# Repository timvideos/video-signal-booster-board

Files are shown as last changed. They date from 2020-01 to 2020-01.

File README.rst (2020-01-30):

Video Booster Board
===================

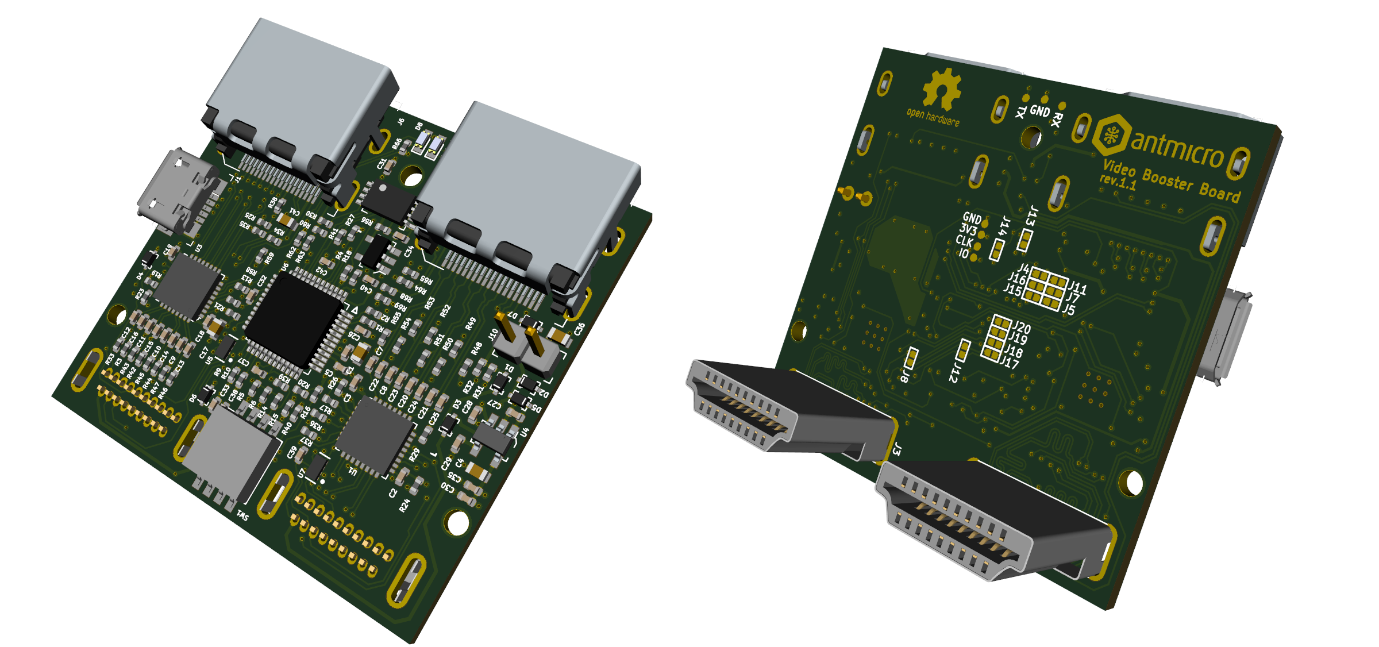
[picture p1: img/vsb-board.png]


Overview: 
---------

This repository contains a KiCad PCB project for an open hardware board design that allows to improve the quality of HDMI video signals transmitted over long cables.

Key features: 
-------------

* HDMI signal preconditioning with a pair of `PTN3363 <https://www.nxp.com/docs/en/data-sheet/PTN3363.pdf>`_ HDMI level shifters.
* Signal equalization controlled with on-board DIP-Switch
* On-board SiLabs `EFM32HG322F64 <https://www.silabs.com/documents/public/data-sheets/efm32hg-datasheet.pdf>`_ MCU for interactive control and board monitoring
* Supports different EDID connection scenarios

Mechanical layout and dimensions
--------------------------------

The board has been mechanically optimised for usage with the `Numato Opsis <https://hdmi2usb.tv/numato-opsis/>`_ open video capture device.
It is possible to use it with different platforms using HDMI extender cables.

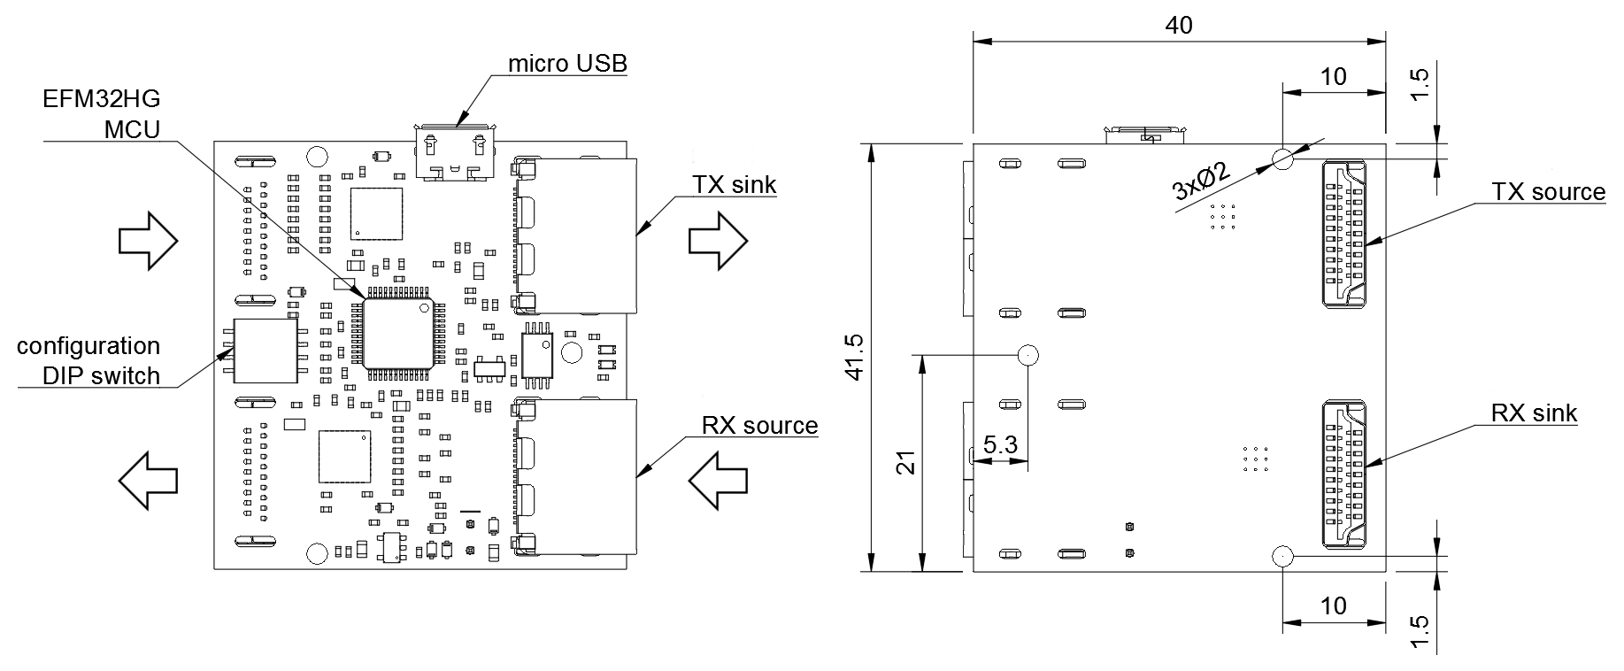
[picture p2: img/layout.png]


It follows the data flow diagram presented below:



Getting Started
---------------

Please refer to KiCad schematic files for more information regarding hardware functionalities implemented in the design.
The PCB layout has been defined with a 4-layer stackup.
Please check the geometry of differential traces implemented in the design with stackup offered by PCB vendor for optimal impedance match of HDMI traces.
There is a BOM document generated from the schematics and shared in this repository.
Please short the ``J5,J7,J8,J12`` solder jumpers on the bottom side of the PCB.
This will relay the EDID signals on both HDMI channels from input to output.
Short the ``J11,J4`` jumpers if you plan to experiment with the provided example MCU firmware.
This will make the on-board MCU accessible on EDID bus driven from ``J2`` HDMI input connector.
Please check the schematics and software codebase for any other jumper configuration.

Example firmware
----------------

The EFM32 MCU used in the design comes with a factory programmed ``AN0042`` bootloader.
In order to  make the MCU compatible with the provided example firmware it is advisable to replace the default bootloader with `Toboot <https://github.com/im-tomu/toboot>`_ 
over SWD interface using `OpenOCD <http://openocd.org/>`_.
The SWD signals from the MCU are exposed on test pads marked with ``IO`` and ``CLK`` on the bottom side of the Video Booster Board.
Additionally there are test pads with system ground and power supply exposed next to them.

To upload the ``Toboot`` bootloader, please follow this `instruction <https://github.com/im-tomu/toboot/tree/master/openocd>`_.
Be aware that the provided flashing instruction was originally created for a different hardware platform so the SWD connection wiring differs a little.

There is an ``example-firmware`` folder included in this repository, which contains a sample firmware driven by the RTOS derived from the `Zephyr project <https://www.zephyrproject.org/>`_.
The firmware makes the on-board EFM32 MCU act as an EDID slave for the transmitting device.

In order to build the example firmware please use the following commands::

     git clone https://github.com/antmicro/video-signal-booster-board
     cd video-signal-booster-board
     git submodule update --init --recursive
     cd example-firmware      
     python3 -m pip install -r zephyr/scripts/requirements.txt                                    
     wget https://github.com/zephyrproject-rtos/sdk-ng/releases/download/v0.10.3/zephyr-sdk-0.10.3-setup.run
     chmod +x zephyr-sdk-0.10.3-setup.run                                  
     ./zephyr-sdk-0.10.3-setup.run -- -d <zephyr_installation_path>                      
     export ZEPHYR_TOOLCHAIN_VARIANT=zephyr                                
     export ZEPHYR_SDK_INSTALL_DIR=<zephyr_installation_path>
     source zephyr/zephyr-env.sh
     west init -l zephyr
     west update
     make

Once the firmware is compiled, connect the micro USB cable to the Video Booster Board and upload the firmware using the following command::

     dfu-util -d 1209:70b1 -D build/zephyr/zephyr.bin

Please note that in this setup the firmware doesn't stick permanently. After a power cycle a bootloader will start again. This simplifies the developing process.

The example firmware makes the MCU on Video Booster Board accessible on I2C/EDID bus slave device under the address of ``0x3a`` (7-bit notation).
It's possible to test the I2C/EDID communication by connecting an I2C master device to TX source HDMI connector (``J2``).
The example firmware makes MCU offer a single 8-bit configuration register.
Two least significant bits of this register control the states of the ``TX_EQ0`` and ``TX_EQ1`` signals that define the equalization settings of ``U3`` HDMI level shifter.
The states of those signals are also displayed on ``D8`` ``D9`` LEDs installed on board.

A sample Python code that would drive the MCU over I2C bus is::

     python
     import smbus
     bus = smbus.SMBus(<i2c_bus_number>)
     bus.write_byte_data(0x3a, 0x00, 0x03)

3D-printable enclosure
----------------------

There is also a 3D-printable enclosure available in the ``3d-models`` directory.
The enclosure allows the electronics to be covered and attaches the Video Booster Board to the Numato board installed in a typical thin mini-ITX chassis.

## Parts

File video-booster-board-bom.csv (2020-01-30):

Id | Designator | Package | Quantity | Designation
1 | J9,J6 | HDMI_A_Female_685119134923 | 2 | 685119134923_
2 | R68,R20,R64,R62,R25,R27,R18 | 0402-res | 7 | R_27k_0402
3 | J12,J5,J14,J13,J8,J7 | SolderJumper-0.6x1.4mm | 6 | solder_jumper
4 | J3,J2 | CHDMI-AMSS-01-C-Vertical-mod1 | 2 | CHDMI-AMSS-01-C-Vertical
5 | U2 | TSSOP-8_W4.4mm | 1 | TPS2110APW
6 | CLK,IO,3V3,GND | Testpoint_smd_0_75mm | 4 | TP_SMD_0_75MM
7 | R21,R32,R35,R59,R58,R23,R26,R29,R34,R36,R37,R39,R40,R31,R9,R10 | 0402-res | 16 | R_10k_0402
8 | C27,C32,C40,C39,C38,C31,C33,C35,C2,C7,C8,C25,C24,C23,C22,C21,C20,C3,C12,C9,C10,C11,C19,C18,C16,C15,C14,C13 | 0402-cap | 28 | C_100n_0402_6V3
9 | U6 | TQFP-48_7x7mm | 1 | EFM32HG322F64
10 | C5,C42,C34,C37,C26,C6 | 0402-cap | 6 | C_1u_0402
11 | U3,U1 | QFN-32-1EP_5x5mm | 2 | PTN3363
12 | SW1 | 1571983-5 | 1 | 1571983-5
15 | C41,C4,C17 | 0603-cap | 3 | C_10u_0603
16 | C30,C28 | 0402-cap | 2 | C_2u2_0402
17 | R63,R69,R65 | 0402-res | 3 | R_4k7_0402
18 | R60,R24,R5,R6,R14,R15,R19 | 0402-res | 7 | R_100k_0402
19 | J10 | PinHeader_1x2_P2.54mm | 1 | M20-9990246
20 | D6,D5,D4,D3,D2,D1,D7 | SOD-523 | 7 | BAT54-02V-V-G
21 | U7,U5 | PSON50P100X195X50-8N | 2 | NTS0102GT
22 | R67,R66 | 0402-res | 2 | R_330R_0402
23 | IC1 | SOT-23-5 | 1 | INA180A1IDBVT
24 | D9,D8 | LED_0603 | 2 | LG_L29K-G2J1-24-Z
25 | C36,C1 | 0603-cap | 2 | C_4u7_0603
26 | R56 | 0402-res | 1 | R_1R_0402
27 | R54,R51,R55,R43,R53,R52,R50,R49,R48,R47,R46,R44,R45,R3,R42,R33 | 0402-res | 16 | R_49R9_0402
28 | R30 | 0402-res | 1 | R_806k_0402
29 | R38,R41,R4,R16 | 0402-res | 4 | R_100R_0402
30 | C29 | 0402-cap | 1 | C_10n_0402
31 | R13,R17 | 0402-res | 2 | R_12k4_0402
32 | R2,R1 | 0402-res | 2 | R_15R_0402
33 | U4 | SOT-753 | 1 | LP2985-33DBVR
34 | J1 | USB_Micro_B_Female_0473460001 | 1 | 473460001

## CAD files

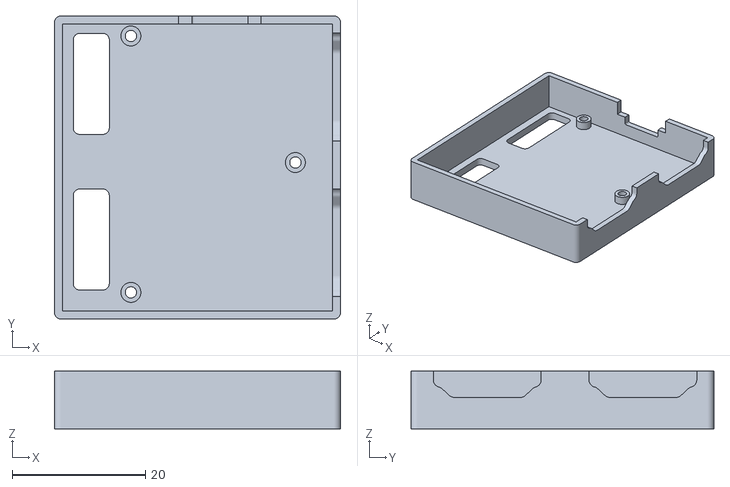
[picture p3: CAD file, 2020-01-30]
3dmodels/enclosure-bottom.stl
43.0 x 45.5 x 8.70

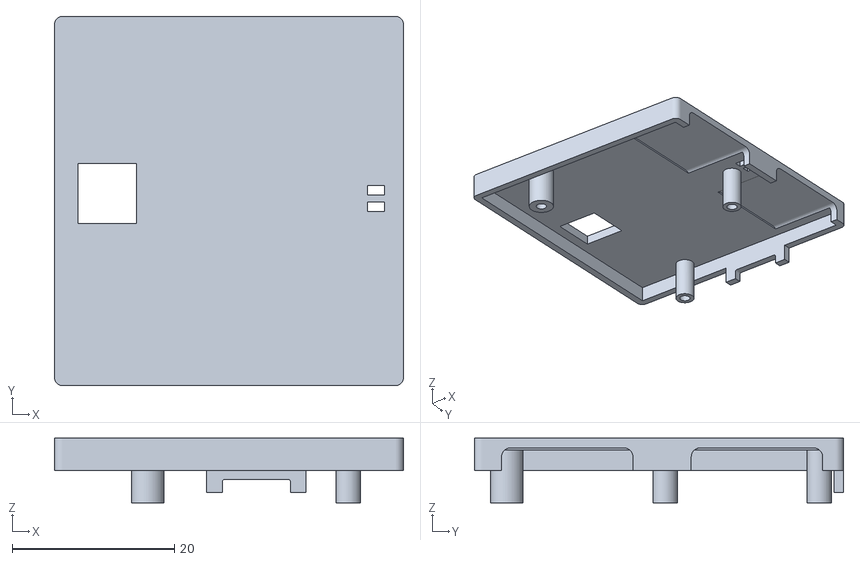
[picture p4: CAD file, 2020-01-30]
3dmodels/enclosure-top.stl
43.0 x 45.5 x 8.00

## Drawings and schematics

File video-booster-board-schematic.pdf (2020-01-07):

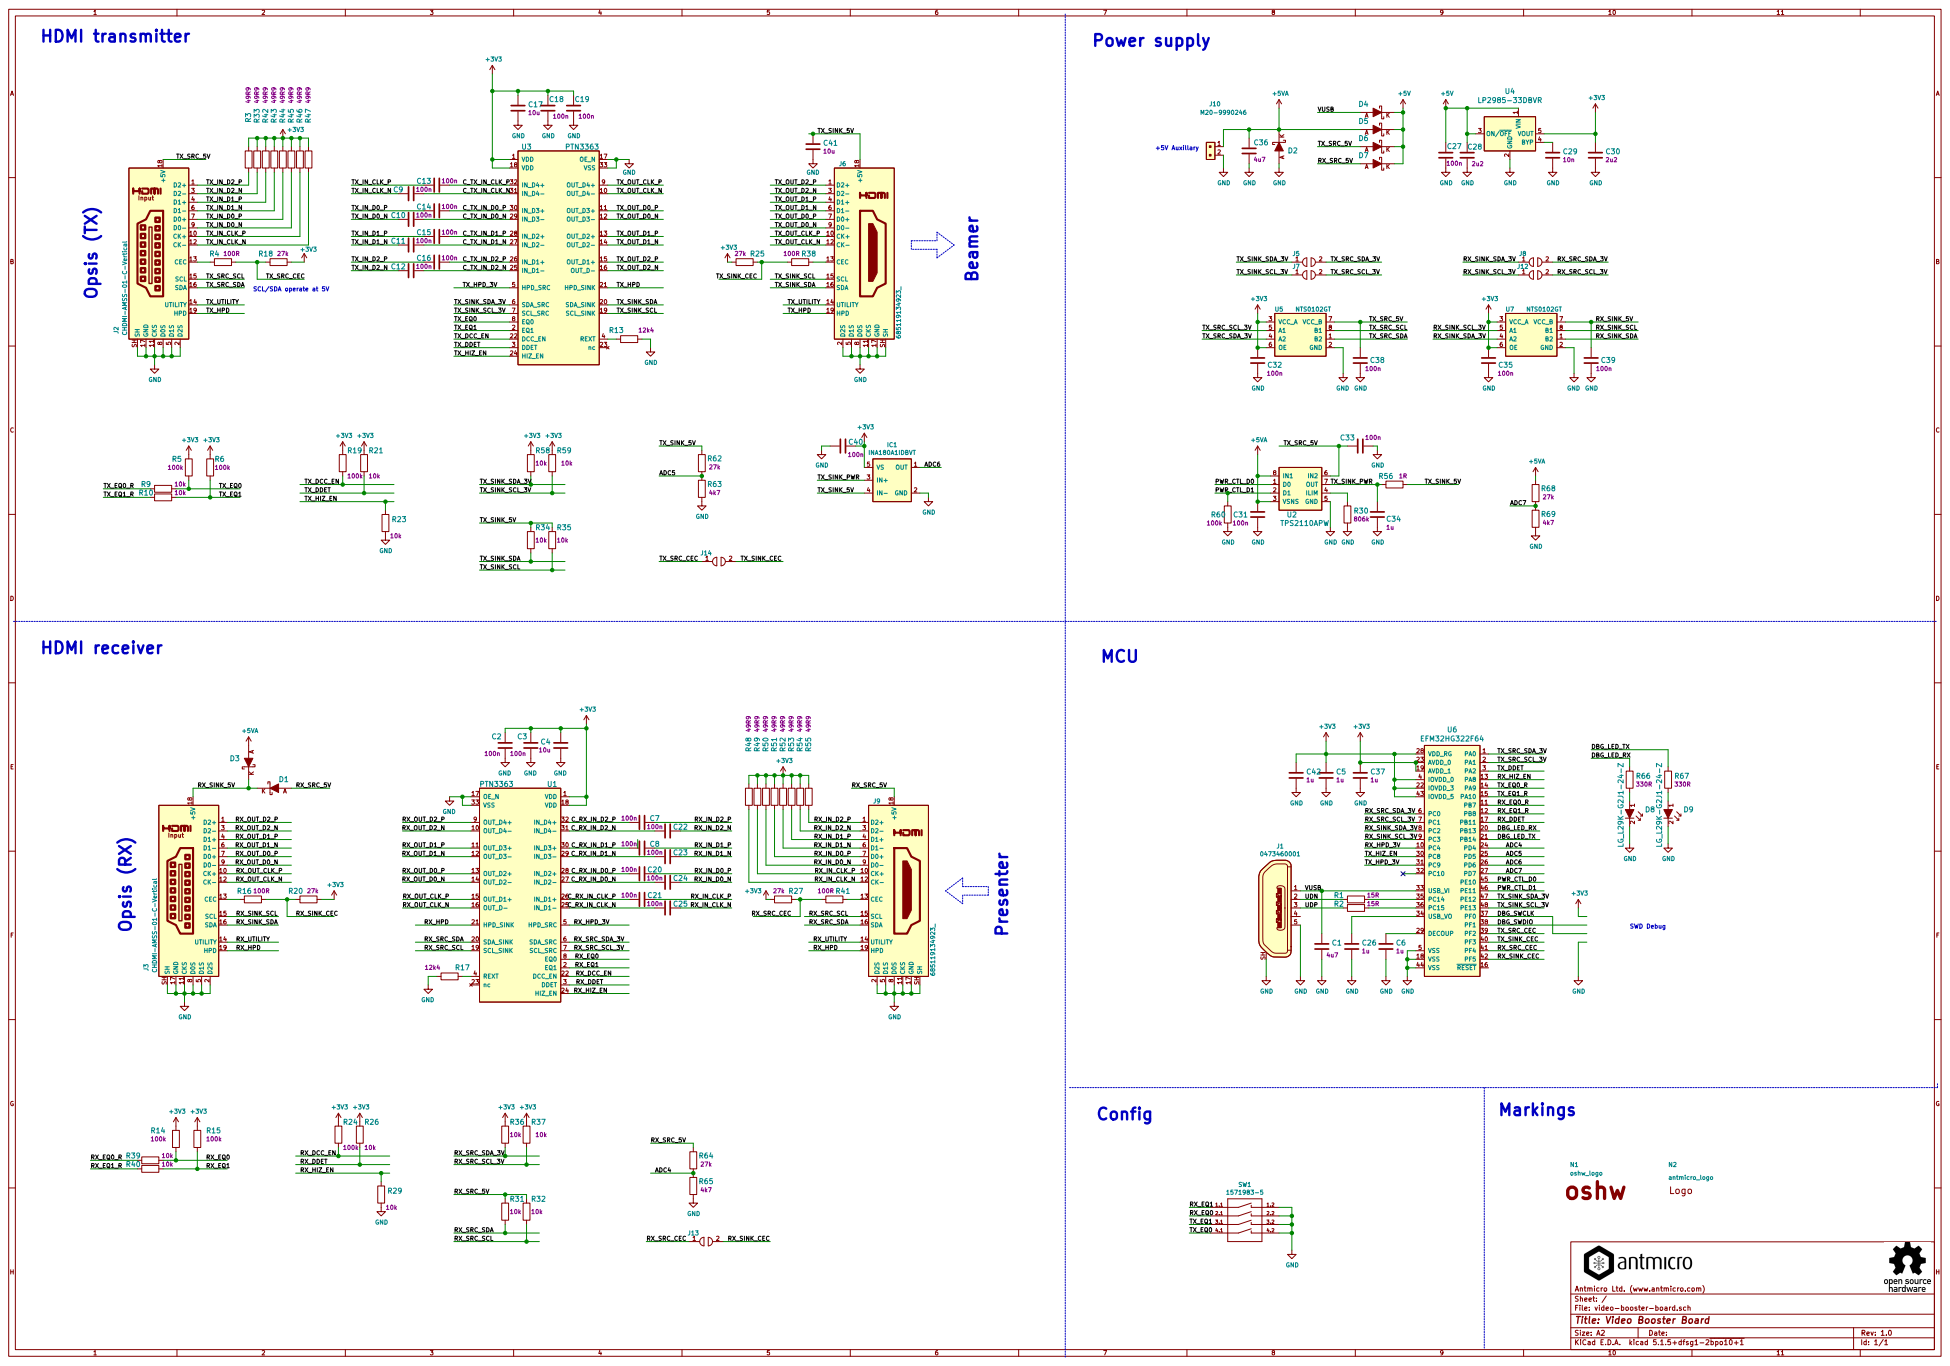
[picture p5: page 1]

8 D0- 9 SH SH J2CHDMI-AMSS-01-C-Vertical

8 D0- 9 SH SH J3CHDMI-AMSS-01-C-Vertical

File: video-booster-board.sch Sheet: / Antmicro Ltd. (www.antmicro.com)

Id: 1/1 Title: Video Booster Board

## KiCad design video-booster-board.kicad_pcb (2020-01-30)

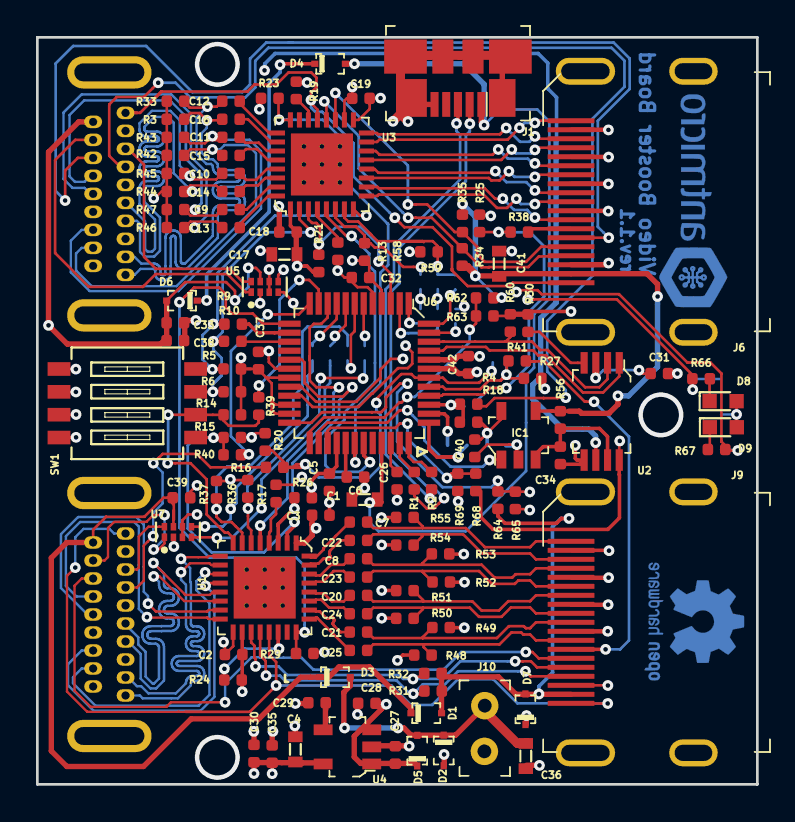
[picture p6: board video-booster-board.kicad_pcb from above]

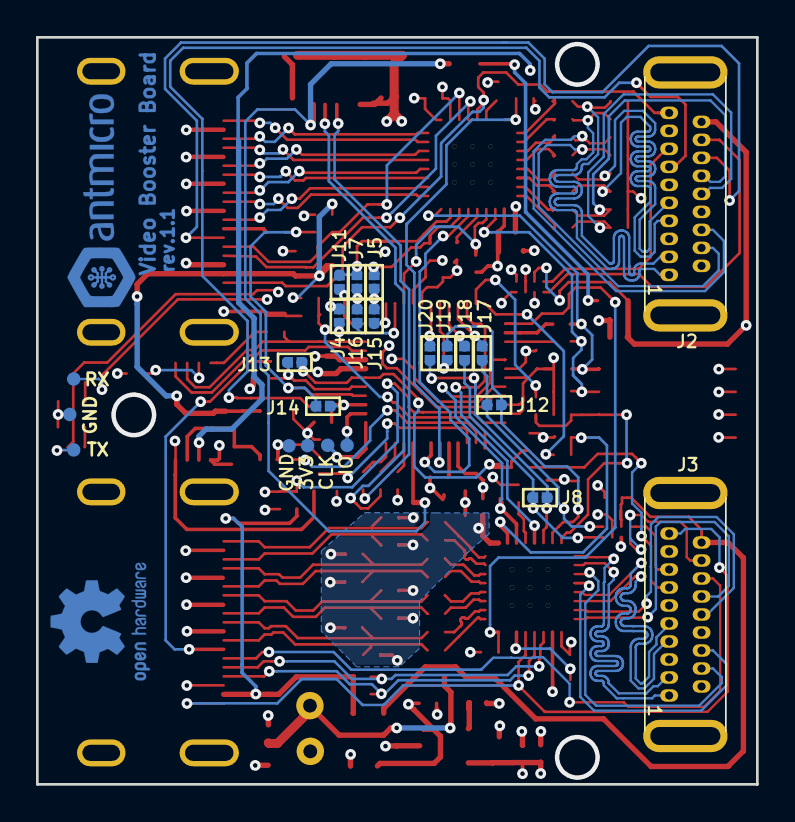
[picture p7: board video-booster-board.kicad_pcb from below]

Board: 4 copper layers, 40.0 x 41.5 mm, 150 parts (25 on the bottom side), 132 nets.

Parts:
3V3: TP_SMD_0_75MM; Testpoint_smd_0_75mm
C1, C36: C_4u7_0603; 0603-cap
C2, C3, C7, C8, C9, C10, C11, C12, C13, C14, C15, C16, C18, C19, C20, C21, C22, C23, C24, C25, C27, C31, C32, C33, C35, C38, C39, C40: C_100n_0402_6V3; 0402-cap
C4, C17, C41: C_10u_0603; 0603-cap
C5, C6, C26, C34, C37, C42: C_1u_0402; 0402-cap
C28, C30: C_2u2_0402; 0402-cap
C29: C_10n_0402; 0402-cap
CLK: TP_SMD_0_75MM; Testpoint_smd_0_75mm
D1, D2, D3, D4, D5, D6, D7: BAT54-02V-V-G; SOD-523
D8, D9: LG_L29K-G2J1-24-Z; LED_0603
GND: TP_SMD_0_75MM; Testpoint_smd_0_75mm
GND#2: TP_SMD_0_75MM; Testpoint_smd_0_75mm
IC1: INA180A1IDBVT; SOT-23-5
IO: TP_SMD_0_75MM; Testpoint_smd_0_75mm
J1: 0473460001; USB_Micro_B_Female_0473460001
J2, J3: CHDMI-AMSS-01-C-Vertical; CHDMI-AMSS-01-C-Vertical-mod1
J4, J5, J7, J8, J11, J12, J13, J14, J15, J16, J17, J18, J19, J20: solder_jumper; SolderJumper-0.6x1.4mm
J6, J9: 685119134923_; HDMI_A_Female_685119134923
J10: M20-9990246; PinHeader_1x2_P2.54mm
N1: oshw_logo; OSHW-Logo2_7.3x6mm_Copper_Mask
N2: antmicro_logo; antmicro-logo_scaled_12mm
R1, R2: R_15R_0402; 0402-res
R3, R33, R42, R43, R44, R45, R46, R47, R48, R49, R50, R51, R52, R53, R54, R55: R_49R9_0402; 0402-res
R4, R16, R38, R41: R_100R_0402; 0402-res
R5, R6, R14, R15, R19, R24, R60: R_100k_0402; 0402-res
R9, R10, R21, R23, R26, R29, R31, R32, R34, R35, R36, R37, R39, R40, R58, R59: R_10k_0402; 0402-res
R13, R17: R_12k4_0402; 0402-res
R18, R20, R25, R27, R62, R64, R68: R_27k_0402; 0402-res
R30: R_806k_0402; 0402-res
R56: R_1R_0402; 0402-res
R63, R65, R69: R_4k7_0402; 0402-res
R66, R67: R_330R_0402; 0402-res
RX: TP_SMD_0_75MM; Testpoint_smd_0_75mm
SW1: 1571983-5
TX: TP_SMD_0_75MM; Testpoint_smd_0_75mm
U1, U3: PTN3363; QFN-32-1EP_5x5mm
U2: TPS2110APW; TSSOP-8_W4.4mm
U4: LP2985-33DBVR; SOT-753
U5, U7: NTS0102GT; PSON50P100X195X50-8N
U6: EFM32HG322F64; TQFP-48_7x7mm

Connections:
+3V3: 3V3.1, C2.2, C3.2, C4.1, C5.1, C17.1, C18.2, C19.2, C30.1, C32.1, C35.1, C37.1, C40.1, C42.1, IC1.5, R3.1, R5.1, R6.1, R14.1, R15.1, R18.2, R19.1, R20.2, R21.1, R24.1, R25.2, R26.1, R27.2, R33.1, R36.1, R37.1, R42.1, R43.1, R44.1, R45.1, R46.1, R47.1, R48.1, R49.1, R50.1, R51.1, R52.1, R53.1, R54.1, R55.1, R58.1, R59.1, U1.1, U1.18, U3.1, U3.18, U4.5, U5.3, U5.6, U6.4, U6.19, U6.22, U6.23, U6.28, U6.43, U7.3, U7.6
+5V: C27.2, C28.1, D4.K, D5.K, D6.K, D7.K, U4.1, U4.3
+5VA: C31.1, C36.1, D2.K, D3.A, D5.A, J10.1, R68.2, U2.3, U2.8
/ADC4: R64.1, R65.2, U6.24
/ADC5: R62.1, R63.2, U6.25
/ADC6: IC1.1, U6.26
/ADC7: R68.1, R69.2, U6.27
/C_RX_IN_CLK_N: C25.1, U1.25
/C_RX_IN_CLK_P: C21.1, U1.26
/C_RX_IN_D0_N: C24.1, U1.27
/C_RX_IN_D0_P: C20.1, U1.28
/C_RX_IN_D1_N: C23.1, U1.29
/C_RX_IN_D1_P: C8.1, U1.30
/C_RX_IN_D2_N: C22.1, U1.31
/C_RX_IN_D2_P: C7.1, U1.32
/C_TX_IN_CLK_N: C9.1, U3.31
/C_TX_IN_CLK_P: C13.1, U3.32
/C_TX_IN_D0_N: C10.1, U3.29
/C_TX_IN_D0_P: C14.1, U3.30
/C_TX_IN_D1_N: C11.1, U3.27
/C_TX_IN_D1_P: C15.1, U3.28
/C_TX_IN_D2_N: C12.1, U3.25
/C_TX_IN_D2_P: C16.1, U3.26
/DBG_LED_RX: R66.1, RX.1, U6.20
/DBG_LED_TX: R67.1, TX.1, U6.21
/DBG_SWCLK: CLK.1, U6.37
/DBG_SWDIO: IO.1, U6.38
/PWR_CTL_D0: U2.1, U6.45
/PWR_CTL_D1: R60.1, U2.2, U6.46
/RX_DCC_EN: R24.2, U1.22
/RX_DDET: R26.2, U1.3, U6.17
/RX_EQ0: R14.2, R39.1, SW1.2.1, U1.8
/RX_EQ0_R: R39.2, U6.11
/RX_EQ1: R15.2, R40.1, SW1.1.1, U1.2
/RX_EQ1_R: R40.2, U6.12
/RX_HIZ_EN: R29.1, U1.24, U6.13
/RX_HPD: J3.19, J9.19, U1.21
/RX_HPD_3V: U1.5, U6.10
/RX_IN_CLK_N: C25.2, J9.12, R48.2
/RX_IN_CLK_P: C21.2, J9.10, R49.2
/RX_IN_D0_N: C24.2, J9.9, R50.2
/RX_IN_D0_P: C20.2, J9.7, R51.2
/RX_IN_D1_N: C23.2, J9.6, R52.2
/RX_IN_D1_P: C8.2, J9.4, R53.2
/RX_IN_D2_N: C22.2, J9.3, R54.2
/RX_IN_D2_P: C7.2, J9.1, R55.2
/RX_OUT_CLK_N: J3.12, U1.16
/RX_OUT_CLK_P: J3.10, U1.15
/RX_OUT_D0_N: J3.9, U1.14
/RX_OUT_D0_P: J3.7, U1.13
/RX_OUT_D1_N: J3.6, U1.12
/RX_OUT_D1_P: J3.4, U1.11
/RX_OUT_D2_N: J3.3, U1.10
/RX_OUT_D2_P: J3.1, U1.9
/RX_SINK_5V: C39.2, D1.K, D3.K, J3.18, U7.7
/RX_SINK_CEC: J13.2, R16.2, R20.1, U6.42
/RX_SINK_SCL: J3.15, U7.8
/RX_SINK_SCL_3V: J12.1, J17.2, U7.5
/RX_SINK_SCL_MCU_3V: J17.1, U6.9
/RX_SINK_SDA: J3.16, U7.1
/RX_SINK_SDA_3V: J8.1, J18.2, U7.4
/RX_SINK_SDA_MCU_3V: J18.1, U6.8
/RX_SRC_5V: D1.A, D7.A, J9.18, R31.1, R32.1, R64.2
/RX_SRC_CEC: J13.1, R27.1, R41.2, U6.41
/RX_SRC_SCL: J9.15, R32.2, U1.19
/RX_SRC_SCL_3V: J12.2, J19.2, R37.2, U1.7
/RX_SRC_SCL_MCU_3V: J19.1, U6.7
/RX_SRC_SDA: J9.16, R31.2, U1.20
/RX_SRC_SDA_3V: J8.2, J20.2, R36.2, U1.6
/RX_SRC_SDA_MCU_3V: J20.1, U6.6
/RX_UTILITY: J3.14, J9.14
/TX_DCC_EN: R19.2, U3.22
/TX_DDET: R21.2, U3.3, U6.3
/TX_EQ0: R5.2, R9.1, SW1.4.1, U3.8
/TX_EQ0_R: R9.2, U6.14
/TX_EQ1: R6.2, R10.1, SW1.3.1, U3.2
/TX_EQ1_R: R10.2, U6.15
/TX_HIZ_EN: R23.1, U3.24, U6.30
/TX_HPD: J2.19, J6.19, U3.21
/TX_HPD_3V: U3.5, U6.31
/TX_IN_CLK_N: C9.2, J2.12, R47.2
/TX_IN_CLK_P: C13.2, J2.10, R46.2
/TX_IN_D0_N: C10.2, J2.9, R45.2
/TX_IN_D0_P: C14.2, J2.7, R44.2
/TX_IN_D1_N: C11.2, J2.6, R43.2
/TX_IN_D1_P: C15.2, J2.4, R42.2
/TX_IN_D2_N: C12.2, J2.3, R33.2
/TX_IN_D2_P: C16.2, J2.1, R3.2
/TX_OUT_CLK_N: J6.12, U3.10
/TX_OUT_CLK_P: J6.10, U3.9
/TX_OUT_D0_N: J6.9, U3.12
/TX_OUT_D0_P: J6.7, U3.11
/TX_OUT_D1_N: J6.6, U3.14
/TX_OUT_D1_P: J6.4, U3.13
/TX_OUT_D2_N: J6.3, U3.16
/TX_OUT_D2_P: J6.1, U3.15
/TX_SINK_5V: C41.1, IC1.4, J6.18, R34.1, R35.1, R56.2, R62.2
/TX_SINK_CEC: J14.2, R25.1, R38.2, U6.40
/TX_SINK_PWR: C34.1, IC1.3, R56.1, U2.7
/TX_SINK_SCL: J6.15, R35.2, U3.19
/TX_SINK_SCL_3V: J7.1, J11.2, R59.2, U3.7
/TX_SINK_SCL_MCU_3V: J11.1, U6.48
/TX_SINK_SDA: J6.16, R34.2, U3.20
/TX_SINK_SDA_3V: J4.2, J5.1, R58.2, U3.6
/TX_SINK_SDA_MCU_3V: J4.1, U6.47
/TX_SRC_5V: C33.2, C38.2, D6.A, J2.18, U2.6, U5.7
/TX_SRC_CEC: J14.1, R4.2, R18.1, U6.39
/TX_SRC_SCL: J2.15, U5.8
/TX_SRC_SCL_3V: J7.2, J16.2, U5.5
/TX_SRC_SCL_MCU_3V: J16.1, U6.2
/TX_SRC_SDA: J2.16, U5.1
/TX_SRC_SDA_3V: J5.2, J15.2, U5.4
/TX_SRC_SDA_MCU_3V: J15.1, U6.1
/TX_UTILITY: J2.14, J6.14
/UDN: J1.2, R1.1
/UDP: J1.3, R2.1
/VUSB: C1.1, D4.A, J1.1, U6.33
GND: C1.2, C2.1, C3.1, C4.2, C5.2, C6.2, C17.2, C18.1, C19.1, C26.2, C27.1, C28.2, C29.2, C30.2, C31.2, C32.2, C33.1, C34.2, C35.2, C36.2, C37.2, C38.1, C39.1, C40.2, C41.2, C42.2, D2.A, D8.2, D9.2, GND.1, GND#2.1, IC1.2, J1.5, J1.SH, J2.2, J2.5, J2.8, J2.11, J2.17, J2.SH, J3.2, J3.5, J3.8, J3.11, J3.17, J3.SH, J6.2, J6.5, J6.8, J6.11, J6.17, J6.SH, J9.2, J9.5, J9.8, J9.11, J9.17, J9.SH, J10.2, R13.1, R17.1, R23.2, R29.2, R30.2, R60.2, R63.1, R65.1, R69.1, SW1.1.2, SW1.2.2, SW1.3.2, SW1.4.2, U1.17, U1.33, U2.5, U3.17, U3.33, U4.2, U5.2, U6.5, U6.18, U6.44, U7.2
unnamed: C6.1, U6.29
unnamed: C26.1, U6.34
unnamed: C29.1, U4.4
unnamed: D8.1, R66.2
unnamed: D9.1, R67.2
unnamed: J2.13, R4.1
unnamed: J3.13, R16.1
unnamed: J6.13, R38.1
unnamed: J9.13, R41.1
unnamed: R1.2, U6.35
unnamed: R2.2, U6.36
unnamed: R13.2, U3.4
unnamed: R17.2, U1.4
unnamed: R30.1, U2.4

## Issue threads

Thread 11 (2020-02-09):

Zephyr firmware doesn't appear on USB?

mithro, 2020-02-09:
@CarlFK was following the tutorial to load the Zephyr firmware onto the board and it didn't seem to enumerate as a USB serial device at all?

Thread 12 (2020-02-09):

Can Opsis communicate / control video the board?

mithro, 2020-02-09:
The Opsis should be able to control the video booster board via the I2C interface.

I believe this hasn't been done yet?

kgugala, 2020-03-25:
the board is accessible via I2C in the HDMI plug (the same the OS uses to read EDID). The device is accessible on `0x3a` address

kgugala, 2020-03-25:
@mithro Apparently you meant something different, can you elaborate?

mithro, 2020-03-25:
How do you modify the Opsis firmware so that it can detect the video booster board and the Opsis console is able to set the video booster level and read the video booster information.

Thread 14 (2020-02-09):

Document the I2C protocol for controlling board

mithro, 2020-02-09:
Related to #12

It would be good to have a Python script which allows a laptop connected to the device via the video connector to control + communicate with the board.

mithro, 2020-02-09:
Looks like there is a start of a protocol at;
https://github.com/antmicro/video-signal-booster-board/blob/bf4c565313b7c16e25c0caa3de4203ac927c29c7/example-firmware/src/main.c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

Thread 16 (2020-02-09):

Firmware should allow read the current / voltage values

mithro, 2020-02-09:
The firmware should allow reading the current and voltage levels and report them via;
 - [ ] USB Serial console.
 - [ ] I2C control interface.

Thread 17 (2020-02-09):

What i2c address should the board apear as?

CarlFK, 2020-02-09:
only monitor plugged in
```
root@cnt4:~# i2cdetect 6
WARNING! This program can confuse your I2C bus, cause data loss and worse!
I will probe file /dev/i2c-6.
I will probe address range 0x03-0x77.
Continue? [Y/n]
     0  1  2  3  4  5  6  7  8  9  a  b  c  d  e  f
00:          -- -- -- -- -- -- -- -- -- -- -- -- --
10: -- -- -- -- -- -- -- -- -- -- -- -- -- -- -- --
20: -- -- -- -- -- -- -- -- -- -- -- -- -- -- -- --
30: -- -- -- -- -- -- -- 37 -- -- 3a -- -- -- -- --
40: -- -- -- -- -- -- -- -- -- 49 -- -- -- -- -- --
50: 50 -- -- -- -- -- -- -- -- 59 -- -- -- -- -- --
60: -- -- -- -- -- -- -- -- -- -- -- -- -- -- -- --
70: -- -- -- -- -- -- -- --                 
```
With device plugged in
```
root@cnt4:~# i2cdetect 6
WARNING! This program can confuse your I2C bus, cause data loss and worse!
I will probe file /dev/i2c-6.
I will probe address range 0x03-0x77.
Continue? [Y/n]
     0  1  2  3  4  5  6  7  8  9  a  b  c  d  e  f
00:          -- -- -- -- -- -- -- -- -- -- -- -- --
10: -- -- -- -- -- -- -- -- -- -- -- -- -- -- -- --
20: -- -- -- -- -- -- -- -- -- -- -- -- -- -- -- --
30: -- -- -- -- -- -- -- 37 -- -- 3a -- -- -- -- --
40: 40 -- -- -- -- -- -- -- -- 49 -- -- -- -- -- --
50: 50 -- -- -- -- -- -- -- -- 59 -- -- -- -- -- --
60: -- -- -- -- -- -- -- -- -- -- -- -- -- -- -- --
70: -- -- -- -- -- -- -- --                 
```

firmware seems to list address as:
https://github.com/antmicro/video-signal-booster-board/blob/bf4c565313b7c16e25c0caa3de4203ac927c29c7/example-firmware/src/main.c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

CarlFK, 2020-02-09:
No monitor plugged in
```
root@cnt4:~# i2cdetect 6
WARNING! This program can confuse your I2C bus, cause data loss and worse!
I will probe file /dev/i2c-6.
I will probe address range 0x03-0x77.
Continue? [Y/n]
     0  1  2  3  4  5  6  7  8  9  a  b  c  d  e  f
00:          -- -- -- -- -- -- -- -- -- -- -- -- --
10: -- -- -- -- -- -- -- -- -- -- -- -- -- -- -- --
20: -- -- -- -- -- -- -- -- -- -- -- -- -- -- -- --
30: -- -- -- -- -- -- -- -- -- -- 3a -- -- -- -- --
40: -- -- -- -- -- -- -- -- -- -- -- -- -- -- -- --
50: -- -- -- -- -- -- -- -- -- -- -- -- -- -- -- --
60: -- -- -- -- -- -- -- -- -- -- -- -- -- -- -- --
70: -- -- -- -- -- -- -- --                 
```

kgugala, 2020-03-25:
there is a note in the README:

```The example firmware makes the MCU on Video Booster Board accessible on I2C/EDID bus slave device under the address of 0x3a (7-bit notation). ```

so the `3a` you're seeing in your dumps should be the devive

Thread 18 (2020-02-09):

Case should have ports labled

CarlFK, 2020-02-09:
the 4 hdmi connectors should have some tx/rx source/sink labelling.

I suggest A,B for the left/right ports to avoid any association with the Opsis "output 1" port.

kgugala, 2020-03-25:
@anowick4 can you take a look on this?

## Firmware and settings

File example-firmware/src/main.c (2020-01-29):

/*
 * Copyright (c) 2019, Antmicro
 *
 * SPDX-License-Identifier: Apache-2.0
 */

#include <zephyr.h>
#include <stdio.h>
#include <drivers/i2c.h>
#include <drivers/uart.h>
#include <stdlib.h>
#include <kernel.h>
#include <drivers/gpio.h>

static struct device *i2c_dev;
static struct device *led0;
static struct device *led1;
static struct device *tx_eq0;
static struct device *tx_eq1;

#define TX_EQ0_PORT DT_GPIO_GECKO_PORTA_NAME
#define TX_EQ0_PIN 9
#define TX_EQ1_PORT DT_GPIO_GECKO_PORTA_NAME
#define TX_EQ1_PIN 10

static int i2c_cb(struct i2c_slave_config *config, uint8_t val)
{
	if (val == 0x0) {
		gpio_pin_write(tx_eq0, TX_EQ0_PIN, 0);
		gpio_pin_write(tx_eq1, TX_EQ1_PIN, 0);
		gpio_pin_write(led0, DT_ALIAS_LED0_GPIOS_PIN, 0);
		gpio_pin_write(led1, DT_ALIAS_LED1_GPIOS_PIN, 0);
	} else if (val == 0x1) {
		gpio_pin_write(tx_eq0, TX_EQ0_PIN, 1);
		gpio_pin_write(tx_eq1, TX_EQ1_PIN, 0);
		gpio_pin_write(led0, DT_ALIAS_LED0_GPIOS_PIN, 1);
		gpio_pin_write(led1, DT_ALIAS_LED1_GPIOS_PIN, 0);
	} else if (val == 0x2) {
		gpio_pin_write(tx_eq0, TX_EQ0_PIN, 0);
		gpio_pin_write(tx_eq1, TX_EQ1_PIN, 1);
		gpio_pin_write(led0, DT_ALIAS_LED0_GPIOS_PIN, 0);
		gpio_pin_write(led1, DT_ALIAS_LED1_GPIOS_PIN, 1);
	} else if (val == 0x3) {
		gpio_pin_write(tx_eq0, TX_EQ0_PIN, 1);
		gpio_pin_write(tx_eq1, TX_EQ1_PIN, 1);
		gpio_pin_write(led0, DT_ALIAS_LED0_GPIOS_PIN, 1);
		gpio_pin_write(led1, DT_ALIAS_LED1_GPIOS_PIN, 1);
	}

	return 0;
}

static const struct i2c_slave_callbacks callbacks = {
        .write_received = i2c_cb,
};

void main(void)
{
	i2c_dev = device_get_binding("I2C_0");

	if (!i2c_dev)
		printf("binding failed\n");

        /* Disable watchdog timer */
        *(uint32_t *)0x40088000UL = 0;

        led0 = device_get_binding(DT_ALIAS_LED0_GPIOS_CONTROLLER);
        led1 = device_get_binding(DT_ALIAS_LED1_GPIOS_CONTROLLER);

        if (!led0 && !led1)
		printf("binding leds failed\n");

	tx_eq0 = device_get_binding(TX_EQ0_PORT);
	tx_eq1 = device_get_binding(TX_EQ1_PORT);

	if (!tx_eq0 && !tx_eq1)
		printf("binding equalizer setting pins failed\n");

        gpio_pin_configure(led0, DT_ALIAS_LED0_GPIOS_PIN, GPIO_DIR_OUT);
        gpio_pin_write(led0, DT_ALIAS_LED0_GPIOS_PIN, 0);
        gpio_pin_configure(led1, DT_ALIAS_LED1_GPIOS_PIN, GPIO_DIR_OUT);
        gpio_pin_write(led1, DT_ALIAS_LED1_GPIOS_PIN, 0);

	gpio_pin_configure(tx_eq0, TX_EQ0_PIN, GPIO_DIR_OUT);
	gpio_pin_write(tx_eq0, TX_EQ0_PIN, 0);
	gpio_pin_configure(tx_eq1, TX_EQ1_PIN, GPIO_DIR_OUT);
	gpio_pin_write(tx_eq1, TX_EQ1_PIN, 0);

        struct i2c_slave_config cfg;
        cfg.address = 0x74;
        cfg.callbacks = &callbacks;

        int ret = i2c_slave_register(i2c_dev, &cfg);

        if (ret) {
                printf("Couldn't register as slave! \n");
        }

        while(1) {
                k_sleep(1000);
        }
}

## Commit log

2019-10-23 Initial commit, dongle schematics
    [fpga-ecosystem-video-booster-board.kicad_pcb, fpga-ecosystem-video-booster-board.sch]
2019-10-23 LED and I2C input option added. Annotated sch.
    [fpga-ecosystem-video-booster-board.sch]
2019-10-24 PCB update issues solved. PTN gnd connection fix
    [fpga-ecosystem-video-booster-board.kicad_pcb, fpga-ecosystem-video-booster-board.sch]
2019-10-24 Board shape, initial component layout
    [fpga-ecosystem-video-booster-board.kicad_pcb]
2019-10-30 Schematics with two channels. I2Cs connected directly
    [fpga-ecosystem-video-booster-board.sch]
2019-10-30 New board shape, initial placement
    [fpga-ecosystem-video-booster-board.kicad_pcb]
2019-10-30 Channels flipped for 1-side component placement
    [fpga-ecosystem-video-booster-board.kicad_pcb, fpga-ecosystem-video-booster-board.sch]
2019-10-30 Component layout for double, one sided dongle
    [fpga-ecosystem-video-booster-board.kicad_pcb, fpga-ecosystem-video-booster-board.sch]
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2019-10-31 Updated footprints with new 3D models
    [video-booster-board.kicad_pcb]
2019-11-06 Schematic modified to allow EDID override, I2C switching, hot plug detect, CEC receive/transmitt
    [video-booster-board.sch]
2019-11-06 Initial placement of new components. Diff lanes routed
    [video-booster-board.kicad_pcb, video-booster-board.sch]
2019-11-06 Key features description added. Programming connector changed to smaller
    [video-booster-board.kicad_pcb, video-booster-board.sch]
2019-11-06 Updated feature list, Added PDF schematics
    [video-booster-board.sch]
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2019-11-13 Updated pinout proposal for a 48-pin MCU (with passthrough communication)
    [video-booster-board.sch]
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2019-11-13 Removed old version of MCU
    [video-booster-board.sch]
2019-11-14 I2C and CEC reconnected to pass through MCU (independent ports)
    [video-booster-board.sch]
2019-11-14 Power management options added
    [video-booster-board.sch]
2019-11-14 Current sensing opamp added
    [video-booster-board.sch]
2019-11-15 Pinout adjustments. Placement of new components
    [video-booster-board.kicad_pcb, video-booster-board.sch]
2019-11-18 Schematic sheet changed to A2, added schematic sections
    [video-booster-board.sch]
2019-11-18 Added notes to HDMI/EDID
    [video-booster-board.sch]
2019-11-20 VDD replaced with +3V3
    [video-booster-board.sch]
2019-11-20 CEC clamp diodes added. Open hardware logo added
    [video-booster-board.kicad_pcb, video-booster-board.sch]
2019-11-20 Local libraries generated. SCH and PCB relinked to local libraries
    [video-booster-board.kicad_pcb, video-booster-board.sch]
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2019-11-20 Cleanup, updated schematic PDF
    [video-booster-board.sch]
2019-11-22 Added pulldown on PWR_CTL_D1 and TVS protection on USB
    [video-booster-board.sch]
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2019-11-22 PCB routing: HDMI,control, USB
    [video-booster-board.kicad_pcb, video-booster-board.sch]
2019-11-25 Routing completed. Minor changes in control pins placement
    [video-booster-board.kicad_pcb, video-booster-board.sch]
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2019-11-25 Design Rules errors resolved
    [video-booster-board.kicad_pcb]
2019-11-25 Component designators arranged on PCB
    [video-booster-board.kicad_pcb]
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2019-11-26 Additional decoupling on MCU adn TX_SINK_5V added
    [video-booster-board.kicad_pcb, video-booster-board.sch]
2019-11-26 OSHW logo and board name added on PCB
    [video-booster-board.kicad_pcb, video-booster-board.sch]
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2019-11-28 Opsis side HDMI connector type changed. Board shape adjusted, DC jack added
    [video-booster-board.kicad_pcb, video-booster-board.sch]
2019-11-29 Pass-through jumpers for I2C added
    [video-booster-board.kicad_pcb, video-booster-board.sch]
2019-11-29 Pass-through jumpers for CEC added
    [video-booster-board.kicad_pcb, video-booster-board.sch]
2019-12-02 MCU type update. PCB marking update
    [video-booster-board.kicad_pcb, video-booster-board.sch]
2019-12-03 updated local project libs
    [video-booster-board.kicad_pcb, video-booster-board.sch]
2019-12-04 HDMI connector 3d model updated
    [video-booster-board.kicad_pcb]
2019-12-16 Updated libs and 3D vis links in PCB file
    [video-booster-board.kicad_pcb, video-booster-board.sch]
2019-12-19 Opsis side HDMI connectors changed to 90 deg
    [video-booster-board.kicad_pcb, video-booster-board.sch]
2019-12-19 Board re-routed after change
    [video-booster-board.kicad_pcb]
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2019-12-20 J2/J3 references corrected on F.Silk
    [video-booster-board.kicad_pcb]
2020-01-02 Restored plating on HDMI angular connectors
    [video-booster-board.kicad_pcb]
2020-01-02 Changed TX/RX side of PCB layout
    [video-booster-board.kicad_pcb]
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2020-01-03 SWD changed from pinhead to testpads, routing in progress
    [video-booster-board.kicad_pcb, video-booster-board.sch]
2020-01-06 Updated layout of 3V3 LDO
    [video-booster-board.kicad_pcb]
2020-01-06 Removed barrel jack connector
    [video-booster-board.sch]
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2020-01-06 Removed TVS, all signalls connected
    [video-booster-board.kicad_pcb, video-booster-board.sch]
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2020-01-07 Resolved most of DRC errors
    [video-booster-board.kicad_pcb, video-booster-board.sch]
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2020-01-07 Added Gerber files that validate at Eurocircuits
    [video-booster-board-B_Cu.gbr, video-booster-board-B_Mask.gbr, video-booster-board-B_Paste.gbr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]
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2020-01-08 Added BOM, schematic and gerbers for release 1.1
    [video-booster-board-B_Cu.gbr, video-booster-board-B_Mask.gbr, video-booster-board-B_Paste.gbr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]
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2020-01-20 Equalized HDMI lanes, added testpads with debug uart
    [video-booster-board-B_Cu.gbr, video-booster-board-B_Mask.gbr, video-booster-board-B_Paste.gbr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]
2020-01-21 Resolved DRC issue at Eurocircuits
    [video-booster-board-B_Cu.gbr, video-booster-board-B_Mask.gbr, video-booster-board-B_Paste.gbr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]
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
